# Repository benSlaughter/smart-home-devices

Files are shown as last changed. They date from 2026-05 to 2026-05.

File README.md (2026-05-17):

# Smart Home Devices 🏠

DIY smart home devices built with ESP32, ESPHome, and Home Assistant.

## Devices

### 🎲 Status Dice
A 3D-printed desk cube with an accelerometer inside. Flip it to set your office availability status in Home Assistant. Battery powered with automatic deep sleep.

- **Hardware:** Olimex ESP32-C3-DevKit-Lipo Rev C + SparkFun LIS3DH
- **Config:** [`esphome/status-dice.yaml`](esphome/status-dice.yaml)
- **Features:** 6 face orientations, battery monitoring, USB power detection, charging state, deep sleep on battery, always-on when USB powered

### 🏒 Status Puck
A wall-mounted LED ring indicator outside the office door. Glows different colours based on the dice status — so the family knows when to knock.

- **Hardware:** Olimex ESP32-DevKit-Lipo Rev D + Adafruit NeoPixel Ring 12
- **Config:** [`esphome/status-puck.yaml`](esphome/status-puck.yaml)
- **Features:** 6 status colours (green/red/yellow/blue/purple/off), brightness slider, reads status from dice via HA

## Setup

1. Install [ESPHome](https://esphome.io/)
2. Copy `esphome/secrets.yaml.example` to `esphome/secrets.yaml` and fill in your values
3. Flash: `esphome run esphome/status-dice.yaml`

## Secrets

WiFi credentials and API keys are stored in `esphome/secrets.yaml` (git-ignored). See `esphome/secrets.yaml.example` for the required keys.

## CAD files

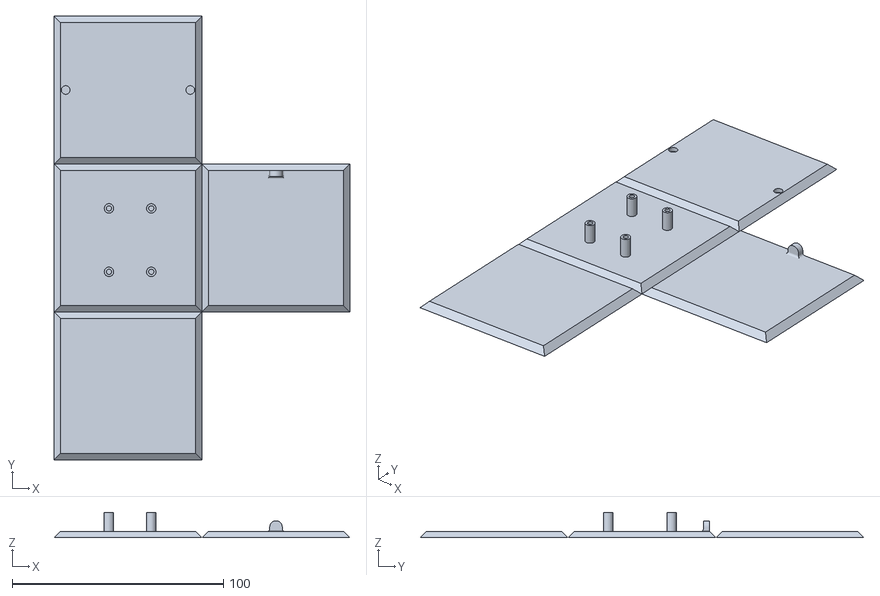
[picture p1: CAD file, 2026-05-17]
3d-models/status-dice/status-dice.stl
140.0 x 210.0 x 12.0

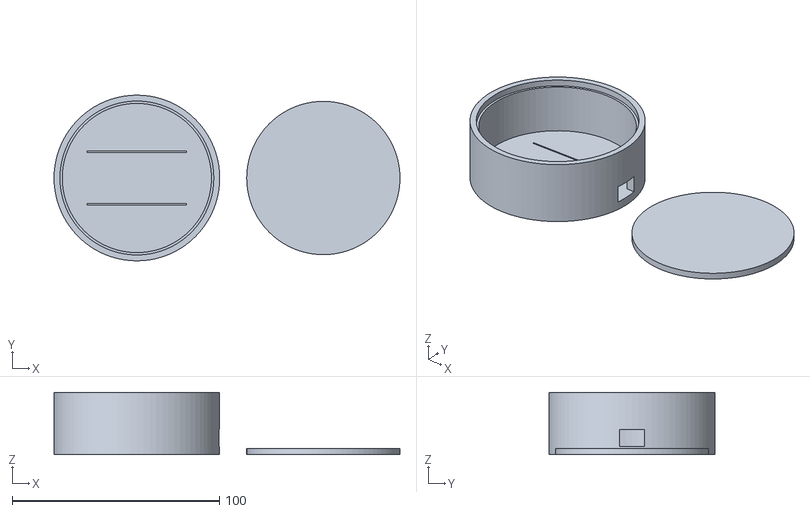
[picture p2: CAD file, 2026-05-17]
3d-models/status-puck/status-puck.stl
167.0 x 80.0 x 30.0

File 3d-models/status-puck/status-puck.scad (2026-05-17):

// Status Puck Enclosure — OpenSCAD
// Circular dish with transparent PLA lid for LED diffusion
// Houses: Olimex ESP32-DevKit-Lipo Rev D + Adafruit NeoPixel Ring 12

/* === Parameters === */

// Overall dimensions
dish_outer_diameter = 80;       // Outer diameter of the dish
dish_wall_thickness = 3;        // Wall thickness (extra 1mm for lid lip)
dish_height = 25;               // Total dish height (without lid)
dish_inner_diameter = dish_outer_diameter - 2 * dish_wall_thickness;

// Lid
lid_height = 3;                 // Lid thickness (transparent PLA)
lid_tolerance = 0.3;            // Gap for press fit

// NeoPixel Ring 12
ring_outer_diameter = 37;       // Adafruit ring outer diameter
ring_inner_diameter = 23;       // Adafruit ring inner hole
ring_height = 3.5;              // Ring PCB thickness
ring_standoff_height = 15;      // Height to position ring near top

// ESP32 board (Olimex ESP32-DevKit-Lipo Rev D)
esp_length = 55;                // Board length
esp_width = 28;                 // Board width (between pin rows)
esp_total_width = 28;           // Width including headers
esp_height = 1.6;               // PCB thickness
esp_pin_length = 11;            // Length of pre-soldered header pins below PCB
esp_clearance = esp_pin_length + 1; // Height above floor for pin clearance

// USB cable exit
cable_slot_width = 12;          // Width for mini USB cable
cable_slot_height = 8;          // Height of slot

// Command strip area
strip_width = 20;               // Width of flat area on back
strip_length = 40;              // Length of flat area on back

$fn = 80;                       // Circle smoothness

/* === Modules === */

module dish_body() {
    difference() {
        // Outer cylinder
        cylinder(d=dish_outer_diameter, h=dish_height);
        
        // Hollow interior
        translate([0, 0, dish_wall_thickness])
            cylinder(d=dish_inner_diameter, h=dish_height);
        
        // Lid recess — cut a step into the top of the wall for the lid to sit in
        translate([0, 0, dish_height - lid_height])
            cylinder(d=dish_inner_diameter + 2 + lid_tolerance, h=lid_height + 1);
        
        // USB cable exit slot — at +X edge of dish wall, inline with ESP board
        translate([dish_outer_diameter/2 - dish_wall_thickness - 1, -cable_slot_width/2, dish_wall_thickness])
            cube([dish_wall_thickness + 2, cable_slot_width, cable_slot_height]);
    }
}

module ring_standoffs() {
    // 3 standoffs to hold the NeoPixel ring near the top
    // Positioned OUTSIDE the ESP32 footprint, near the dish wall
    standoff_diameter = 4;
    mount_radius = dish_inner_diameter/2 - standoff_diameter;
    
    // Place at 90, 210, 330 degrees to avoid the ESP board area and USB slot
    for (angle = [90, 210, 330]) {
        rotate([0, 0, angle])
            translate([mount_radius, 0, dish_wall_thickness])
                cylinder(d=standoff_diameter, h=ring_standoff_height);
    }
}

module esp_mount() {
    // Friction rail channels — the header pins slot into grooves
    // Board drops in from above, pins locate it precisely
    pin_row_spacing = 25.4;       // Distance between the two pin rows (centre to centre)
    channel_width = 3;            // Width of each channel (fits header pin row)
    channel_depth = esp_pin_length - 1; // Depth of channel (pins sit in but don't bottom out)
    board_length = esp_length;
    channel_tolerance = 0.3;
    
    // Two parallel channels in the floor of the dish
    // Board oriented along X axis, centred
    for (y_offset = [-pin_row_spacing/2, pin_row_spacing/2]) {
        translate([-board_length/2, y_offset - (channel_width + channel_tolerance)/2, 0])
            cube([board_length, channel_width + channel_tolerance, dish_wall_thickness + channel_depth]);
    }
}

module lid() {
    // Transparent PLA lid — flat disc that sits in the wall recess
    cylinder(d=dish_inner_diameter + 2, h=lid_height);
}

module command_strip_flat() {
    // Flat area on the bottom for command strip adhesion
    translate([-strip_length/2, -strip_width/2, 0])
        cube([strip_length, strip_width, 0.01]);
}

/* === Assembly === */

// Uncomment the part you want to export for printing:

// Main dish body
///*
difference() {
    dish_body();
    // Cut pin channels into the floor
    esp_mount();
}
//*/

// Lid — print separately in transparent PLA
// Translate beside the dish for printing
/*
translate([dish_outer_diameter + 10, 0, 0])
    lid();
*/

// Both together for preview
/*
difference() {
    color("DimGray") dish_body();
    esp_mount();
}
color("LightBlue", 0.5)
    translate([0, 0, dish_height - lid_height])
        lid();
*/

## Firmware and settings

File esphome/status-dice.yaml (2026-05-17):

# Status Dice — ESPHome Configuration
# Olimex ESP32-C3-DevKit-Lipo + SparkFun LIS3DH
# Deep sleeps on battery, stays awake on USB power

esphome:
  name: status-dice
  friendly_name: "Status Dice"
  on_boot:
    - priority: 200
      then:
        - lambda: |-
            auto *bus = id(i2c_bus);
            uint8_t data[2];

            // CTRL_REG1 (0x20): 0x27 = 10Hz ODR, normal mode, all axes enabled
            data[0] = 0x20; data[1] = 0x27;
            bus->write(0x19, data, 2);

            // CTRL_REG2 (0x21): 0x01 = HP filter on INT1
            data[0] = 0x21; data[1] = 0x01;
            bus->write(0x19, data, 2);

            // CTRL_REG3 (0x22): 0x40 = IA1 interrupt on INT1 pin
            data[0] = 0x22; data[1] = 0x40;
            bus->write(0x19, data, 2);

            // CTRL_REG5 (0x24): 0x08 = latch interrupt on INT1
            data[0] = 0x24; data[1] = 0x08;
            bus->write(0x19, data, 2);

            // INT1_THS (0x32): motion threshold (~250mg)
            data[0] = 0x32; data[1] = 0x10;
            bus->write(0x19, data, 2);

            // INT1_DURATION (0x33): minimum duration (1 sample)
            data[0] = 0x33; data[1] = 0x01;
            bus->write(0x19, data, 2);

            // INT1_CFG (0x30): 0x2A = OR of X/Y/Z high events (movement on any axis)
            data[0] = 0x30; data[1] = 0x2A;
            bus->write(0x19, data, 2);

            // Read INT1_SRC (0x31) to clear any pending interrupt
            uint8_t reg = 0x31;
            uint8_t dummy;
            bus->write(0x19, &reg, 1);
            bus->read(0x19, &dummy, 1);

        # Wait for readings to stabilise and WiFi to connect
        - delay: 3s
        # Force sensor updates
        - component.update: battery_voltage
        - component.update: accel_x
        - component.update: accel_y
        - component.update: accel_z
        - delay: 1s
        - component.update: office_status
        - component.update: battery_percent
        # Sleep if on battery, stay awake if USB powered
        - if:
            condition:
              binary_sensor.is_off: usb_powered
            then:
              - delay: 8s
              - deep_sleep.enter: deep_sleep_1

esp32:
  board: esp32-c3-devkitm-1
  framework:
    type: arduino

safe_mode:
  num_attempts: 10
  boot_is_good_after: 5s

logger:
  level: DEBUG

api:
  encryption:
    key: !secret api_key

ota:
  - platform: esphome
    password: !secret ota_password

wifi:
  ssid: !secret wifi_ssid
  password: !secret wifi_password

  ap:
    ssid: "StatusDice-Fallback"
    password: "fallback123"

captive_portal:

# I2C bus — Olimex UEXT pins
i2c:
  id: i2c_bus
  sda: GPIO7
  scl: GPIO3
  scan: false

# Deep sleep — wakes on GPIO0 (LIS3DH INT1 pin)
deep_sleep:
  id: deep_sleep_1
  wakeup_pin:
    number: GPIO0
    mode: INPUT_PULLDOWN
    inverted: false
  # Fallback: wake every 15 minutes even without motion (heartbeat)
  run_duration: 20s
  sleep_duration: 15min

# Read raw accelerometer values from LIS3DH via I2C
sensor:
  # Battery voltage — GPIO4 (ADC1_CH4) via jumper wire from bat_sens pad
  # Voltage divider on board: multiply by 2 to get actual battery voltage
  - platform: adc
    pin: GPIO4
    name: "Dice Battery Voltage"
    id: battery_voltage
    update_interval: never
    attenuation: 12db
    unit_of_measurement: "V"
    accuracy_decimals: 2
    filters:
      - multiply: 2.0

  - platform: template
    name: "Dice Battery"
    id: battery_percent
    update_interval: never
    unit_of_measurement: "%"
    device_class: battery
    accuracy_decimals: 0
    lambda: |-
      float v = id(battery_voltage).state;
      if (isnan(v)) return NAN;
      // LiPo: 4.2V = 100%, 3.0V = 0%
      float pct = (v - 3.0) / (4.2 - 3.0) * 100.0;
      if (pct > 100) pct = 100;
      if (pct < 0) pct = 0;
      return pct;

  - platform: template
    name: "Dice Accel X"
    id: accel_x
    update_interval: 2s
    unit_of_measurement: "m/s²"
    accuracy_decimals: 1
    lambda: |-
      uint8_t raw[2];
      uint8_t reg = 0x28 | 0x80;
      id(i2c_bus).write(0x19, &reg, 1);
      id(i2c_bus).read(0x19, raw, 2);
      int16_t val = (raw[1] << 8) | raw[0];
      return val / 16384.0 * 9.81;

  - platform: template
    name: "Dice Accel Y"
    id: accel_y
    update_interval: 2s
    unit_of_measurement: "m/s²"
    accuracy_decimals: 1
    lambda: |-
      uint8_t raw[2];
      uint8_t reg = 0x2A | 0x80;
      id(i2c_bus).write(0x19, &reg, 1);
      id(i2c_bus).read(0x19, raw, 2);
      int16_t val = (raw[1] << 8) | raw[0];
      return val / 16384.0 * 9.81;

  - platform: template
    name: "Dice Accel Z"
    id: accel_z
    update_interval: 2s
    unit_of_measurement: "m/s²"
    accuracy_decimals: 1
    lambda: |-
      uint8_t raw[2];
      uint8_t reg = 0x2C | 0x80;
      id(i2c_bus).write(0x19, &reg, 1);
      id(i2c_bus).read(0x19, raw, 2);
      int16_t val = (raw[1] << 8) | raw[0];
      return val / 16384.0 * 9.81;
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

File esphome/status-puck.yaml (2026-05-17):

# Status Puck — ESPHome Configuration
# Olimex ESP32-DevKit-Lipo Rev D + Adafruit NeoPixel Ring 12
# Wall-mounted LED indicator outside office door

esphome:
  name: status-puck
  friendly_name: "Status Puck"

esp32:
  board: esp32dev
  framework:
    type: arduino

logger:
  level: DEBUG

api:
  encryption:
    key: !secret api_key

ota:
  - platform: esphome
    password: !secret ota_password

wifi:
  ssid: !secret wifi_ssid
  password: !secret wifi_password

  ap:
    ssid: "StatusPuck-Fallback"
    password: "fallback123"

captive_portal:

# NeoPixel Ring — 12 WS2812B LEDs on GPIO16
light:
  - platform: neopixelbus
    type: GRB
    variant: WS2812X
    pin: GPIO25
    num_leds: 12
    name: "Status Puck Light"
    id: puck_light
    default_transition_length: 500ms
    effects:
      - pulse:
          name: "Slow Pulse"
          transition_length: 2s
          update_interval: 2s
      - pulse:
          name: "Fast Pulse"
          transition_length: 500ms
          update_interval: 500ms
      - strobe:
          name: "Flash"
          colors:
            - state: true
              brightness: 100%
              duration: 200ms
            - state: false
              duration: 200ms
            - state: true
              brightness: 100%
              duration: 200ms
            - state: false
              duration: 1s

# Pull office status from HA
text_sensor:
  - platform: homeassistant
    name: "Office Status"
    id: office_status
    entity_id: sensor.status_dice_office_status
    on_value:
      then:
        - script.execute: update_puck_colour

# Brightness control — slider in HA (0-100%)
number:
  - platform: template
    name: "Puck Brightness"
    id: puck_brightness
    icon: "mdi:brightness-6"
    unit_of_measurement: "%"
    min_value: 5
    max_value: 100
    step: 5
    initial_value: 30
    optimistic: true
    restore_value: true
    on_value:
      then:
        - script.execute: update_puck_colour

script:
  - id: update_puck_colour
    then:
      - lambda: |-
          auto status = id(office_status).state;
          float bright = id(puck_brightness).state / 100.0;

          if (status == "not_working") {
            auto call = id(puck_light).turn_off();
            call.perform();
            return;
          }

          auto call = id(puck_light).turn_on();
          call.set_brightness(bright);
          call.set_effect("none");

          if (status == "available") {
            call.set_rgb(0.0, 1.0, 0.0);
          } else if (status == "meeting") {
            call.set_rgb(1.0, 0.0, 0.0);
          } else if (status == "focusing") {
            call.set_rgb(1.0, 1.0, 0.0);
          } else if (status == "on_break") {
            call.set_rgb(0.0, 0.5, 1.0);
          } else if (status == "afk") {
            call.set_rgb(0.6, 0.0, 1.0);
          } else {
            // Unknown - Do nothing!
            return;
          }

          call.perform();

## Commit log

2026-05-17 Initial commit: Status Dice and Status Puck ESPHome configs
    - Status Dice: ESP32-C3 + LIS3DH accelerometer, 6-face orientation detection
    - Status Puck: ESP32 + NeoPixel Ring 12, LED status indicator
    - Secrets template and gitignore
2026-05-17 Add 3D models directory with status puck enclosure
    [status-puck.scad, status-puck.stl]
2026-05-17 Add status dice enclosure STL
    [status-dice.stl]
